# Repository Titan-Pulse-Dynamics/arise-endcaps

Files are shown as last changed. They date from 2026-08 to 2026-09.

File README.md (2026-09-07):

# ARISE End Cap PCBs
================================

This repository contains the End Cap PCBs for ARISE.

ARISE End Cap PCBs are derived from the OreSat End Cap PCBs developed by Portland State Aerospace Society.

Original project:
https://github.com/oresat/oresat-endcaps

Original license:
CERN Open Hardware Licence Version 2 – Strongly Reciprocal
(CERN-OHL-S v2)

See the project history and upstream branch for provenance.

TPD modifications are identified in CHANGELOG.md and the relevant files and documentation.

# "End Cap" PCBs for OreSat

These are the "end cap" PCBs that attach to the +Z and -Z ends of the satellites. Mostly these are to protect the end cards from "space", as well as to hold the magnetometers (two per end cap) as far as away from ferrous stuff as possible. It's also a good place for backup antennas, specifically patch antennas (S band and GPS L1).

## Features

- Cutouts for deployable antennas
- Double magnetometers.
- Single vertical 10mm tall 1.27 mm connector that plugs into the "end card" card.
    - On the End Cap:  Harwin M55-6001242R 12 pin female vertical connector 
    - On the End Card below: Harwin M55-7011242R 12 pin male vertical connector
- No available RF connectors.

OreSat +Z End Cap Picture

## LICENSE

Copyright the Portland State Aerospace Society, 2024.

This source describes Open Hardware that is licensed under CERN-OHL-S v2, or any later version.

You may redistribute and modify this source and make products using it under the terms of the CERN-OHL-S v2 (https://ohwr.org/cern_ohl_s_v2.txt).

This source is distributed WITHOUT ANY EXPRESS OR IMPLIED WARRANTY, INCLUDING OF MERCHANTABILITY, SATISFACTORY QUALITY AND FITNESS FOR A PARTICULAR PURPOSE. Please see the CERN-OHL-S v2 for applicable conditions.

Source location: <https://github.com/oresat/>

As per CERN-OHL-S v2 section 4, should You produce hardware based on this source, You must where practicable maintain the Source Location visible on the external case of the Gizmo or other products you make using this source.

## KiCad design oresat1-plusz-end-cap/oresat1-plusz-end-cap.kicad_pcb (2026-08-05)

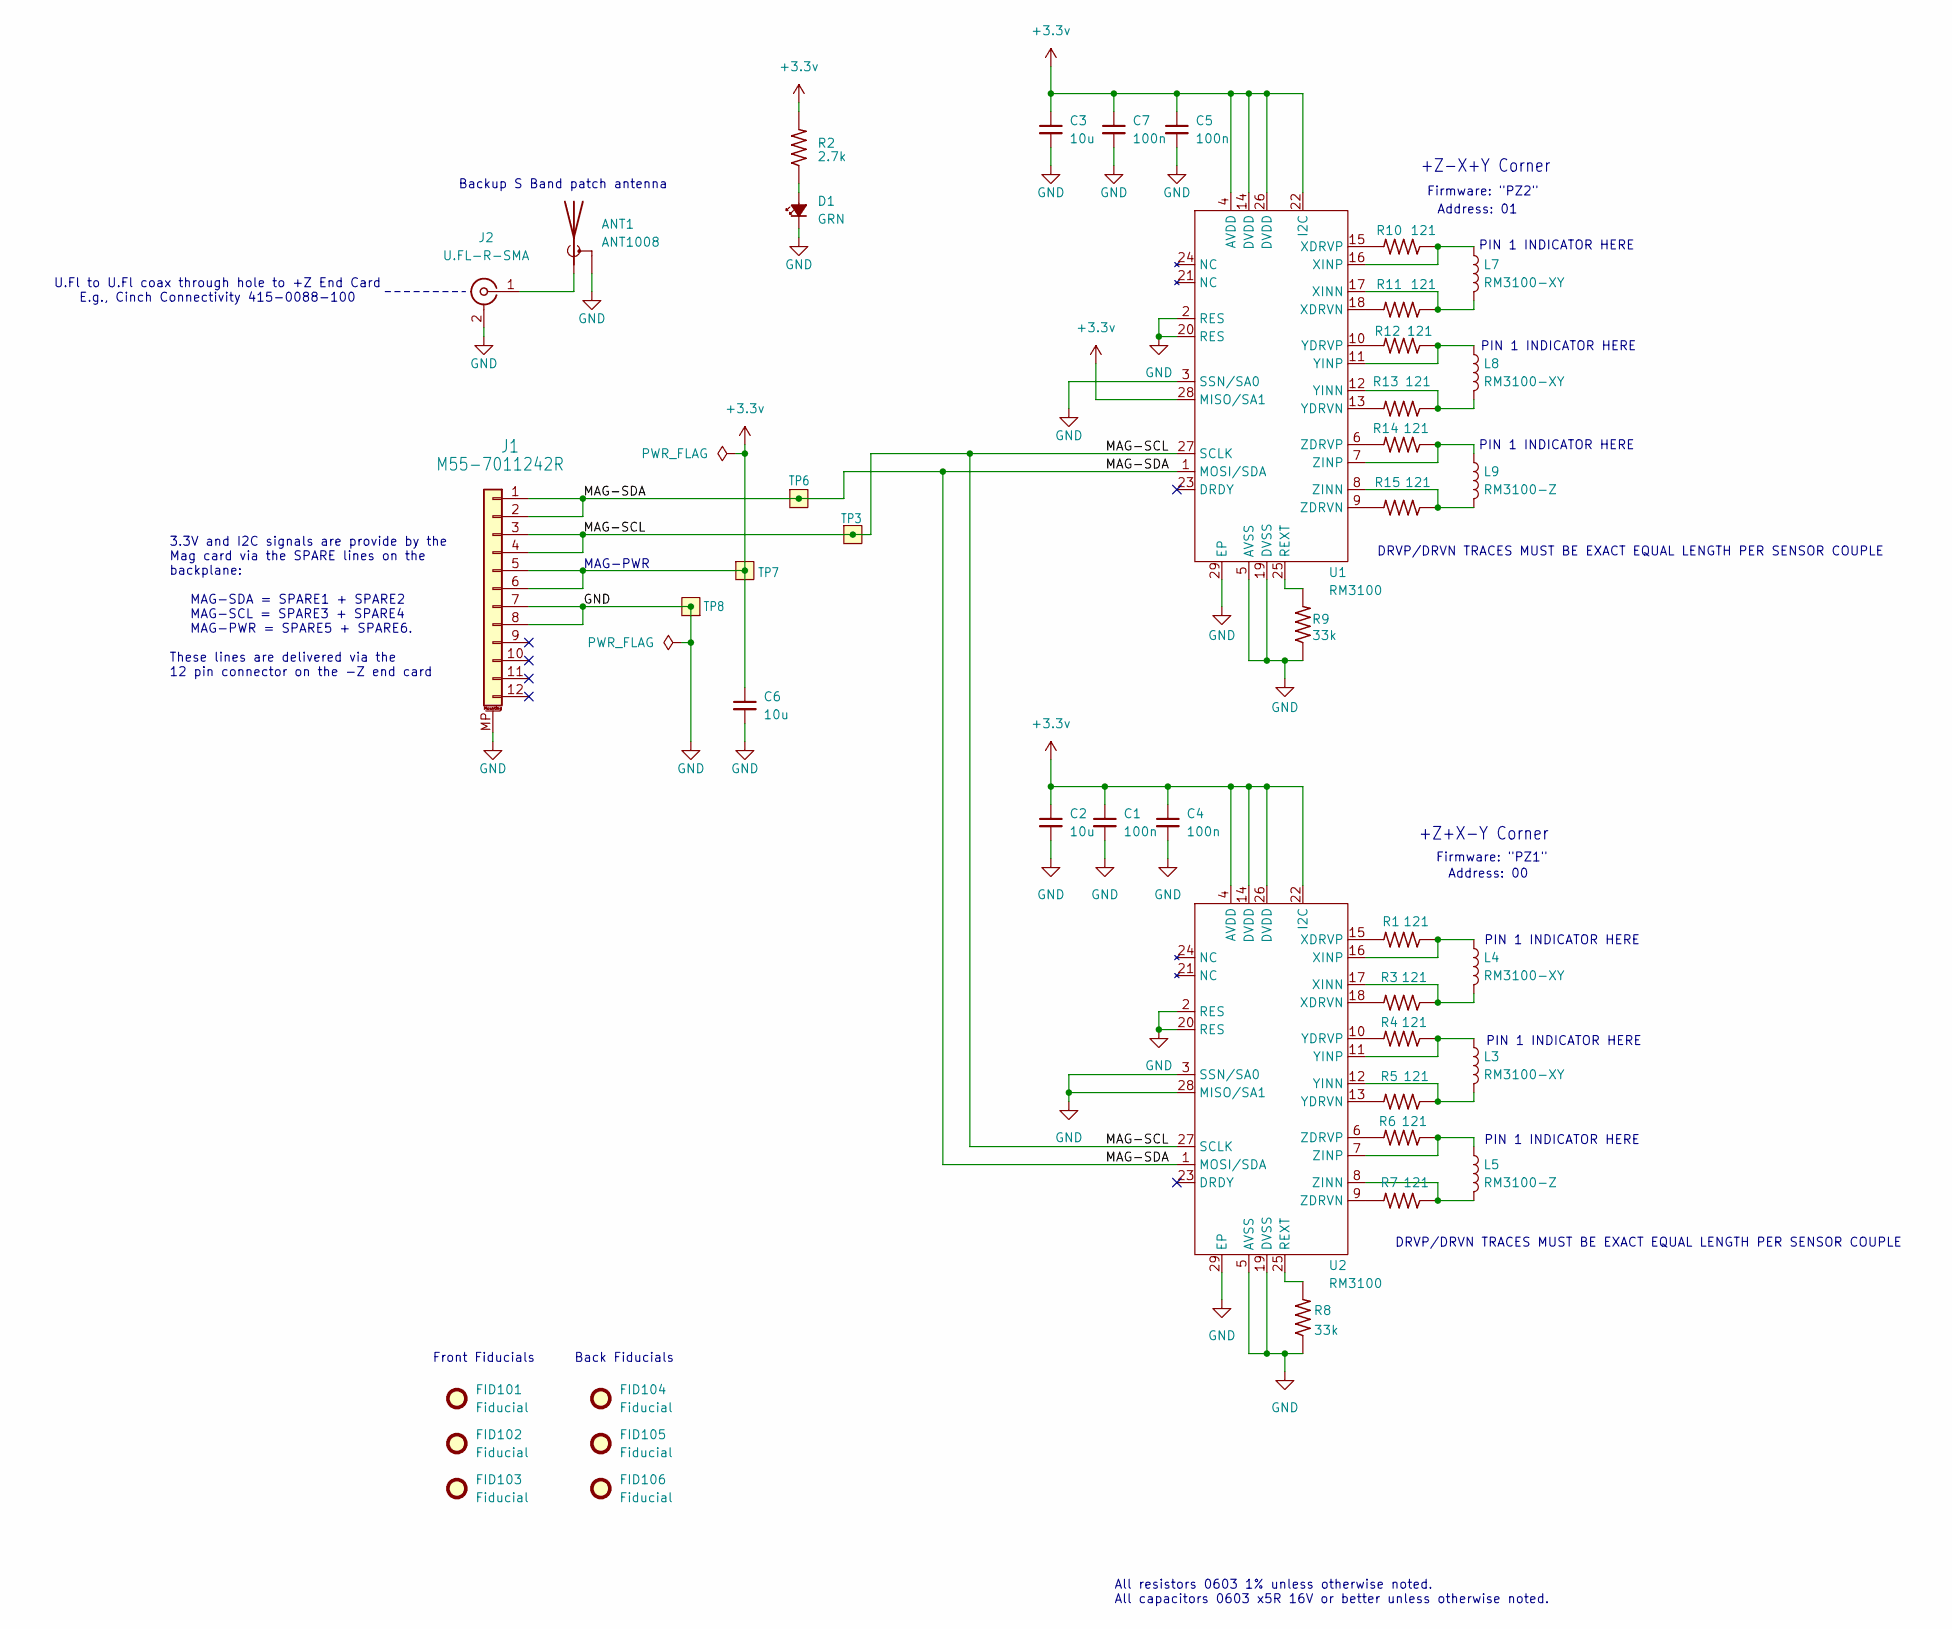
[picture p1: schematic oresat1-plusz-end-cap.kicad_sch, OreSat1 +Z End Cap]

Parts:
ANT1: ANT1008; RFMi-ANT1008-S-Band-Patch; MPN ANT1008
C1, C4, C5, C7: 100n; 0603-C-NOSILK; MPN C0603C104K5RACAUTO
C2, C3, C6: 10u; 0805-C-NOSILK; MPN GRT21BC71E106KE13K
D1: GRN; LED_0603_1608Metric; MPN 150060GS75000
FID101, FID102, FID103, FID104, FID105, FID106: Fiducial; Fiducial_1mm_Mask2mm
J1: M55-7011242R; J-Harwin-M55-7XX1242R; MPN M55-7011242R
J2: U.FL-R-SMA; U.FL_Hirose_U.FL-R-SMT-1_Vertical; MPN U.FL-R-SMT-1(10)
L3, L4, L7, L8: RM3100-XY; RM3100 SEN-XY-f; MFR PNI Sensors
L5, L9: RM3100-Z; RM3100 SEN-Z-f; MFR PNI Sensors
R1, R3, R4, R5, R6, R7, R10, R11, R12, R13, R14, R15: 121; 0603-C-NOSILK; MPN RMCF0603FT121R
R2: 2.7k; 0603-C-NOSILK; MPN RMCF0603FT2K70
R8, R9: 33k; 0603-C-NOSILK; MPN RMCF0603FT33K0
TP3, TP6, TP7, TP8: Test-Point; TestPoint-0.75mm-th; MPN N/A
U1, U2: RM3100; RM3100-MagI2C; MFR PNI Sensors

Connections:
+3.3v: C1.1, C2.1, C3.1, C4.1, C5.1, C6.1, C7.1, J1.5, J1.6, R2.2, TP7.1 (1_1), U1.4 (AVDD), U1.14 (DVDD), U1.22 (I2C), U1.26 (DVDD), U1.28 (MISO/SA1), U2.4 (AVDD), U2.14 (DVDD), U2.22 (I2C), U2.26 (DVDD)
/MAG-SCL: J1.3, J1.4, TP3.1 (1_1), U1.27 (SCLK), U2.27 (SCLK)
/MAG-SDA: J1.1, J1.2, TP6.1 (1_1), U1.1 (MOSI/SDA), U2.1 (MOSI/SDA)
GND: ANT1.2 (Shield), C1.2, C2.2, C3.2, C4.2, C5.2, C6.2, C7.2, D1.1 (K), J1.7, J1.8, J1.MP (MountPin), J2.2 (Ext), R8.1, R9.1, TP8.1 (1_1), U1.2 (RES), U1.3 (SSN/SA0), U1.5 (AVSS), U1.19 (DVSS), U1.20 (RES), U1.29 (EP), U2.2 (RES), U2.3 (SSN/SA0), U2.5 (AVSS), U2.19 (DVSS), U2.20 (RES), U2.28 (MISO/SA1), U2.29 (EP)
unnamed: ANT1.1 (A), J2.1 (In)
unnamed: D1.2 (A), R2.1
unnamed: R9.2, U1.25 (REXT)
unnamed: R11.2, U1.18 (XDRVN)
unnamed: R10.2, U1.15 (XDRVP)
unnamed: L7.2, R11.1, U1.17 (XINN)
unnamed: L7.1, R10.1, U1.16 (XINP)
unnamed: R13.2, U1.13 (YDRVN)
unnamed: R12.2, U1.10 (YDRVP)
unnamed: L8.2, R13.1, U1.12 (YINN)
unnamed: L8.1, R12.1, U1.11 (YINP)
unnamed: R15.2, U1.9 (ZDRVN)
unnamed: R14.2, U1.6 (ZDRVP)
unnamed: L9.2, R15.1, U1.8 (ZINN)
unnamed: L9.1, R14.1, U1.7 (ZINP)
unnamed: R8.2, U2.25 (REXT)
unnamed: R3.2, U2.18 (XDRVN)
unnamed: R1.2, U2.15 (XDRVP)
unnamed: L4.2, R3.1, U2.17 (XINN)
unnamed: L4.1, R1.1, U2.16 (XINP)
unnamed: R5.2, U2.13 (YDRVN)
unnamed: R4.2, U2.10 (YDRVP)
unnamed: L3.2, R5.1, U2.12 (YINN)
unnamed: L3.1, R4.1, U2.11 (YINP)
unnamed: R7.2, U2.9 (ZDRVN)
unnamed: R6.2, U2.6 (ZDRVP)
unnamed: L5.2, R7.1, U2.8 (ZINN)
unnamed: L5.1, R6.1, U2.7 (ZINP)

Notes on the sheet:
PIN 1 INDICATOR HERE
Firmware: "PZ2"
DRVP/DRVN TRACES MUST BE EXACT EQUAL LENGTH PER SENSOR COUPLE
+Z-X+Y Corner
U.Fl to U.Fl coax through hole to +Z End Card E.g., Cinch Connectivity 415-0088-100
Front Fiducials
All resistors 0603 1% unless otherwise noted. All capacitors 0603 x5R 16V or better unless otherwise noted.
Address: 01
3.3V and I2C signals are provide by the Mag card via the SPARE lines on the backplane: MAG-SDA = SPARE1 + SPARE2 MAG-SCL = SPARE3 + SPARE4 MAG-PWR = SPARE5 + SPARE6. These lines are delivered via the 12 pin connector on the -Z end card
Back Fiducials
Address: 00
Firmware: "PZ1"
+Z+X-Y Corner
Backup S Band patch antenna
MAG-PWR

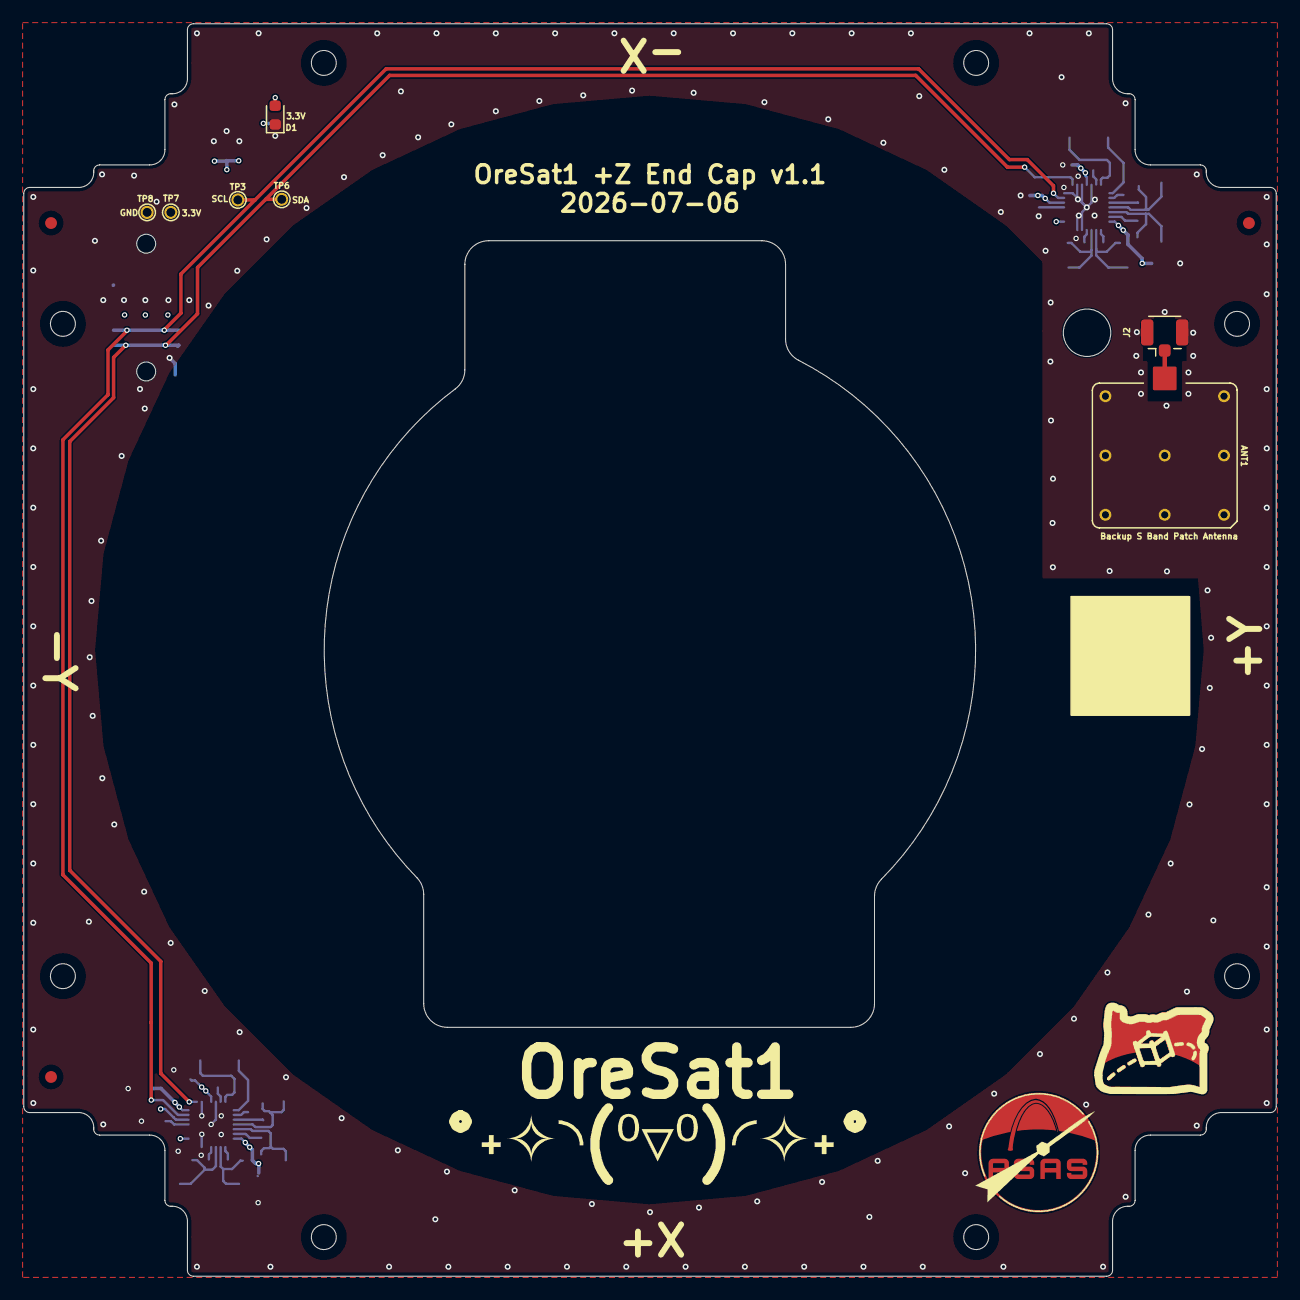
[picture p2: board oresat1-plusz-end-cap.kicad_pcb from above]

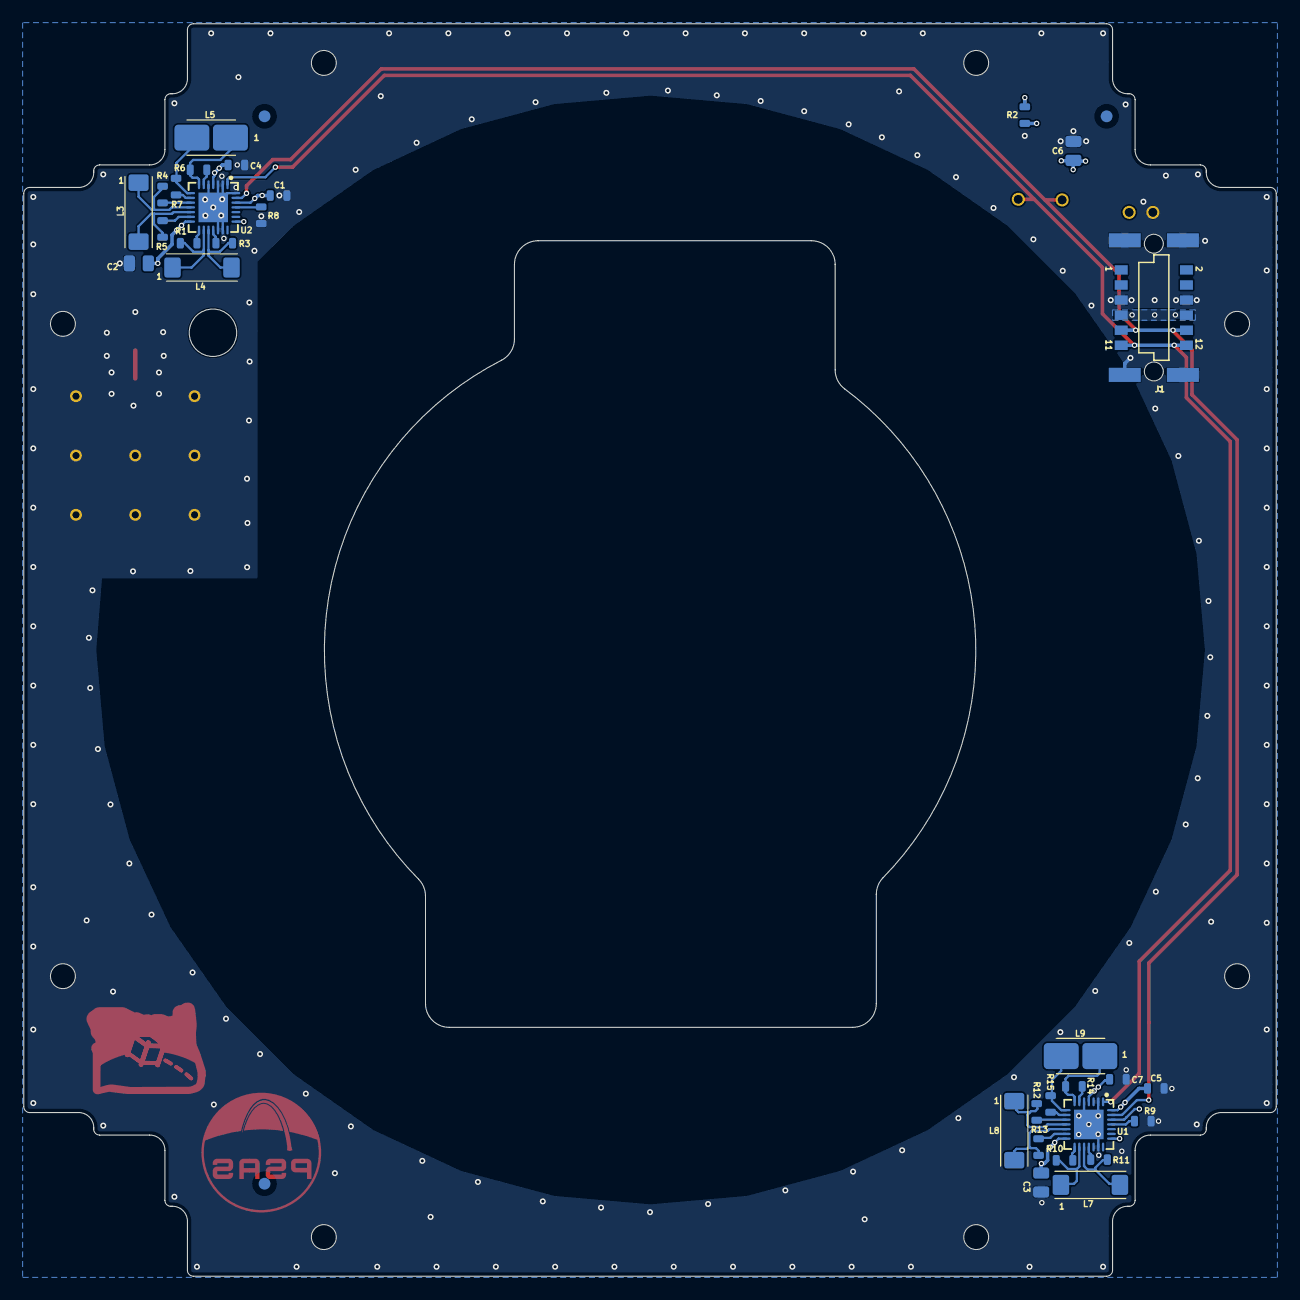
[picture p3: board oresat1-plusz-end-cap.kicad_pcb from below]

Board: 4 copper layers, 105.6 x 105.6 mm, 53 parts (34 on the bottom side), 32 nets.

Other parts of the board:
@HOLE4, @HOLE4#2, @HOLE4#3, @HOLE4#4, @HOLE4#5, @HOLE4#6, @HOLE4#7, @HOLE4#8: MountingHole_2.1mm
LOGO1: PSAS_LOGO_10X10

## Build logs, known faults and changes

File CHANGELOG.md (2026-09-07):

# CHANGE LOG

2026-09-07  
- Repository forked from OreSat End Caps. 
- ARISE project established.
- Original License added as md file
- No design modifications yet.

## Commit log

2026-08-05 OreSat1 +Z End Cap updates
    Fixed SDA/SCL issue, updated to v1.1.
    [oresat1-plusz-end-cap.kicad_pcb, oresat1-plusz-end-cap.kicad_sch]
2026-09-07 ARISE Project Initiation
    Readme amended to reflect TPD's derivative design start
    Changelog.md added to track high-level changes
    Original License added as md file
